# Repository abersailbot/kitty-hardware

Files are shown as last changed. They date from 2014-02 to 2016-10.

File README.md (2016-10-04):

kitty-hardware 
===================================================================================================================================================================

Files relating to Kitty's hardware

This currently contains:

  * [Sails](sails) - Files for the sails
  * [Hull](hull) - Files used in the construction of the hull

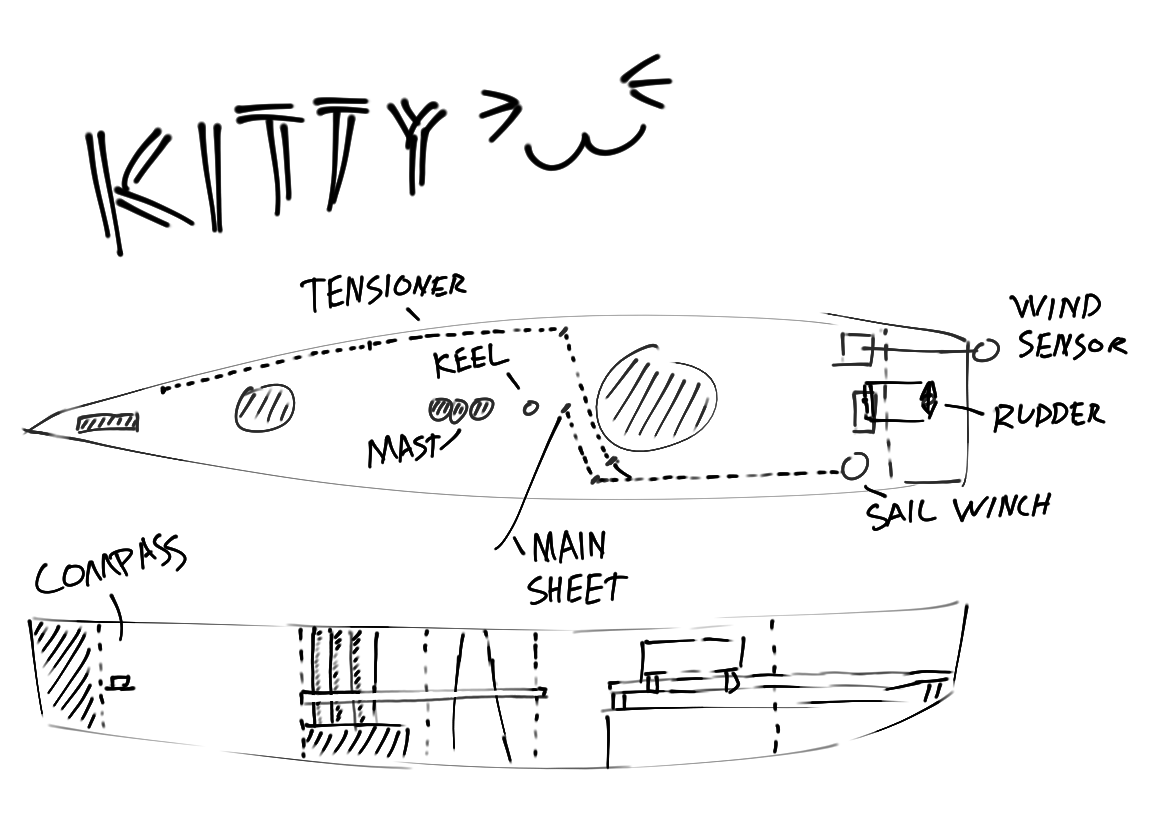
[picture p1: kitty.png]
kitty


Unless specified otherwise, the files contained within are licenced under [CC BY
4.0](http://creativecommons.org/licenses/by/4.0/). See [COPYING](COPYING) for
the full licence.

Weights:
  * Boat with most of the stuff in - 13 kilos
  * Keel - 15 kilos

  * box:
    * base > 29 kilos
    * lid 19 kilos
    * 2.09m x 0.72m x 0.60m

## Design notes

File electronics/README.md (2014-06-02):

Electorics
==========

Box connectors
--------------

###Plug 1
  1. Rudder Power (7.2v)
  2. Rudder Ground
  3. Rudder Servo Data
  4. 
  5. 
  6. Multiplexor Power (6v)
  7. Sail Winch Ground
  8. Sail Winch Live (7.2v)
  9. Sail Winch Data
  10.
  11. Multiplexor Ground
  12.

###Plug 2
  1. Wifi Ground
  2. Wifi Data-
  3. Wifi Data+
  4. Wifi Power (5v)
  5. 
  6. Compass SDA
  7. Compass Ground
  8. Rowind Data
  9. Rowind Ground
  10. Rowind Power (14.4v)
  11. Compass SCL
  12. Compass Power (5v)

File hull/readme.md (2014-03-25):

Hull
----

These are the files used in the construction of the hull.

`hull.igs` was created by [Paul
Miller](http://www.usna.edu/Users/naome/phmiller/), and is public domain.

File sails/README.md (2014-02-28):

sails
=====

Kitty's sails, made using [Sailcut](http://www.sailcut.com/). Currently two sails planned:

  * `heavy_air.saildef` - for heavy winds
  * `light_air.saildef` - for light winds

The sails wrap around the mast, so add an extra 83mm (circumference of the mast)
+ 40mm (leech hem) from the mast edge of the sail.

Output formats for printing are stored in [output](output).

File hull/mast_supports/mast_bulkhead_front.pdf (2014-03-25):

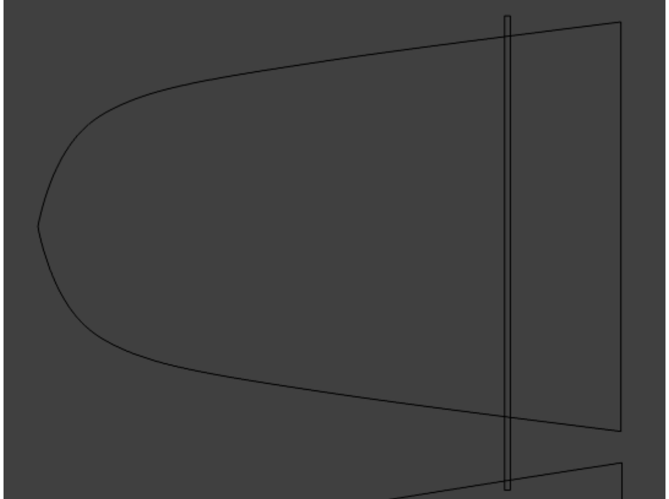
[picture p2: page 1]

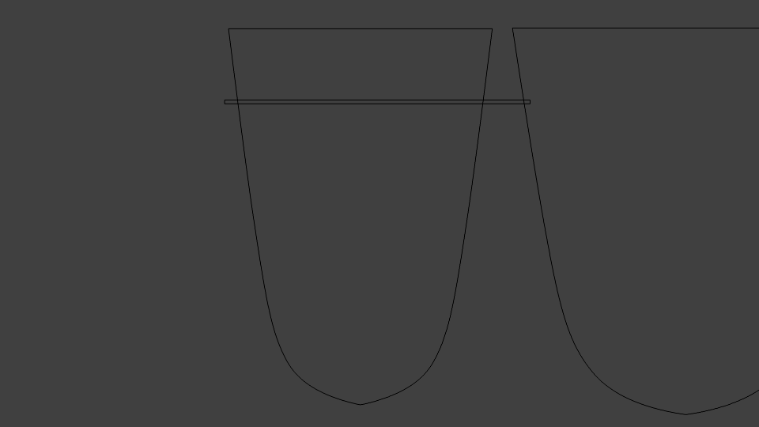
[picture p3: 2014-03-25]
hull/mast_supports/mast_bulkhead.png

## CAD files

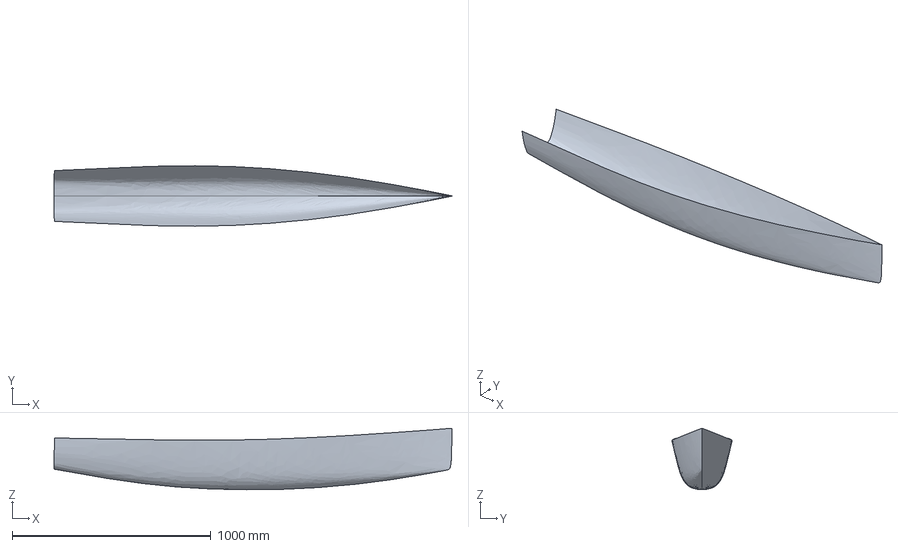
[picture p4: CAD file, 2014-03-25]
hull/hull.igs
2004.0 x 304.7 x 309.7 mm

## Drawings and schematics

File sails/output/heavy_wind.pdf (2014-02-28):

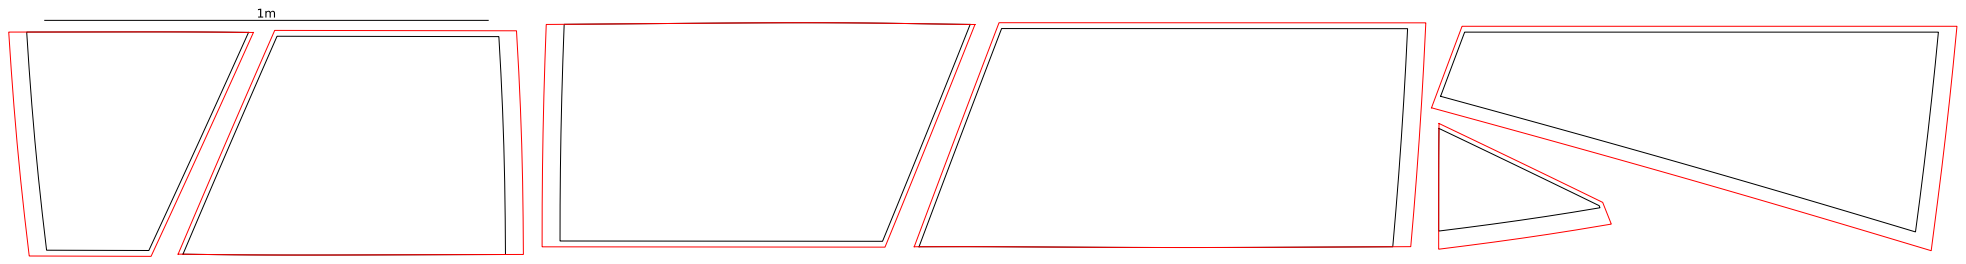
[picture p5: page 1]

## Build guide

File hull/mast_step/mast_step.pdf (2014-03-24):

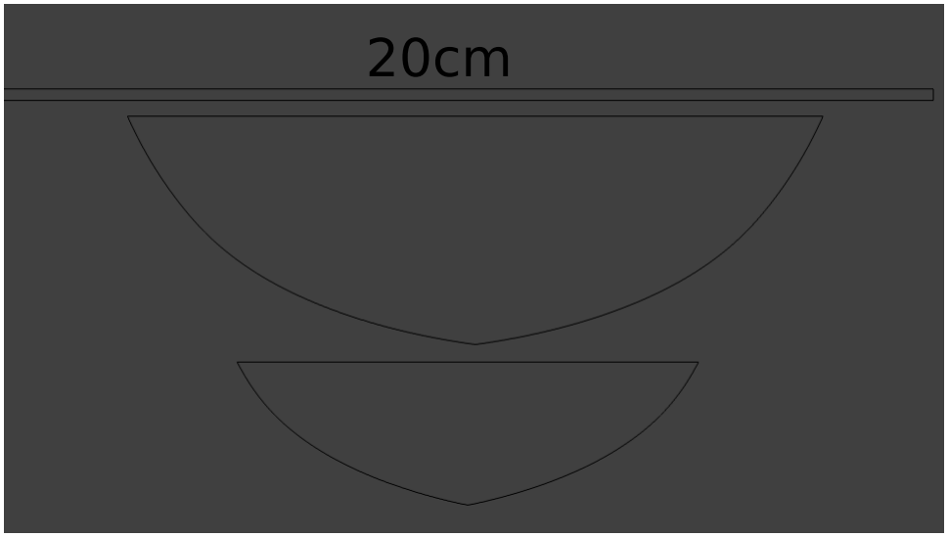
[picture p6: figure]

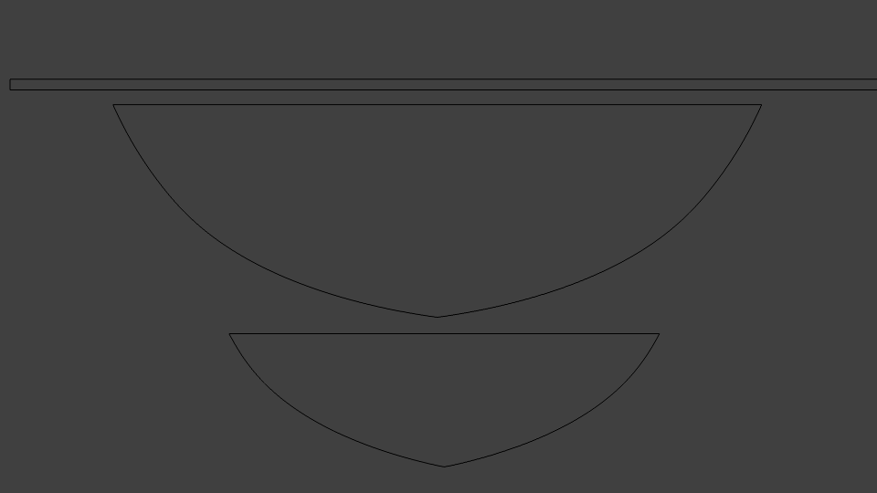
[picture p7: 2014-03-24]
hull/mast_step/mast_step.png

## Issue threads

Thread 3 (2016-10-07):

Investigate Leak

TomGC96, 2016-10-07:
There is a chance that the hull is leaking into the front compartment.

Danyc0, 2016-11-24:
It was first noticed in 2014 in some pretty intense wind, which was pushing the bow well under the water. Testing should probably involve submerging the deck, at least at the bow including past where the the fore-hatch is

ciridae7, 2016-11-30:
We did a water test, found the front hatch was leaking. See issue: https://github.com/abersailbot/kitty-hardware/issues/24

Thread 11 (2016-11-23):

Shopping list

JaffaCakes6, 2016-11-23:
- Nylon screws, bolts, nuts
- Bungee cord elastic stuff (The stuff that's on Dewi)

kragniz, 2016-11-23:
Spray paint for the hull.

kragniz, 2016-11-23:
I just updated the issue to use checkboxes.

JaffaCakes6, 2016-11-30:
Paint for #12, what colour?

naturesyouth, 2016-11-30:
is spray paint the best choice?

ciridae7, 2016-11-30:
O-ring, for front hatch, need to check dimensions. Also vaseline.

Danyc0, 2016-12-01:
@naturesyouth: yea, spray paint will be good. @JaffaCakes6: Kitty is already mostly yellow, I'd guess she just needs more of that

JaffaCakes6, 2017-01-21:
Updated to include more items.

naturesyouth, 2017-01-21:
Are you guys going sand and reprime kitty?

jackwebb6, 2017-02-22:
Undecided. At this point I think we're just going for seafaring paint rather than pretty paint, but I'm not sure.

Also add more items, and purchasing some too.

NicholasRostant, 2017-02-22:
If you're hunting for seafaring paint Marine Enamel is probably what you want.

TomGC96, 2017-02-22:
Yes certainly some sort of marine paint, not any old paint - it'll peel off like crazy.

NicholasRostant, 2017-02-22:
Gelcoat would probably be way too heavy in the kind of thicknesses it's usually applied. I'd recommend something along the lines of [http://www.pettitpaint.com/product.asp?id=274](this stuff), which I've used before, its topside paint but should be more than durable enough.

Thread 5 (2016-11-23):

Secure compass

JSpringett, 2016-11-23:

Danyc0, 2016-11-24:
Please make sure it's an HMC6343, the CMPS10's caused us so much hassle in San Francisco 2014. (Although there is now a CMPS11 which should probably be investigated and TOUGHLY TESTED)

MFrankland, 2016-11-24:
The compass is attached but not quite secure, my hands are too large to properly tighten the screws

adaszymczak, 2016-11-30:
Screws has been changed - issue fixed

Closed 2016-11-30.

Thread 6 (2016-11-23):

Captain Morgan for Kitty

JSpringett, 2016-11-23:

JaffaCakes6, 2016-11-23:
If the bodged Canada board (w/ ribbon cable) works the same, easy peasy.

If not (for now, supposedly), just edit the software to cope.

Danyc0, 2016-11-23:
Please don't use the bodged canada board for Kitty. Spin a new one! The canada board is not very well protected in terms of grounding and reverse polarity protection. Also it's much harder to use for debugging because it's missing some of the more useful LEDs

JSpringett, 2016-11-23:
Its only temporary will we wait for the new board to be sorted out.

naturesyouth, 2016-11-23:
i think its a good idea to use the old shield to get both boats as similar as possible as soon as possible, but given the large number of unknowns in the boat i would feel better if you transplanted the board from dewi into kitty as it is so much safer.

Danyc0, 2016-11-24:
It's also worth considering though, that Kitty has a lot more room in her boxes to fit the old ribbon-cable/stacked version of Captain-Morgan

naturesyouth, 2016-11-24:
yeah but i would feel better trusting kitty to the better assembled 1.2, blowing a pi/battery/anything else would be less than fun, especially as it will be replaced by christmas and we are currently rediscovering how kitty works.

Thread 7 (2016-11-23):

Investigate power source

JSpringett, 2016-11-23:

Danyc0, 2016-11-23:
The ones in kitty are 4*7.2v NiMh. They're in series for the computers to run the RoWind at the right voltage, but in parallel for the servos to give them enough current capacity. (All recalled from 3 year old memories, so take with a pinch of salt)

JSpringett, 2016-11-23:
Cheers Dan

Danyc0, 2016-11-24:
It might be worth switching to having both sets in parallel and using a boost converter to get the voltage needed for the RoWind. This was originally discounted because of the inefficiencies in boost regulators as compared to buck regs, but now, thanks to us having a working PCB (Captain Morgan), it opens lots of doors with regards to very efficient boost regulators. This would allow us to better standardise electronics between the boats (with a Do Not Populate on the boost reg for boats which don't have a RoWind).

naturesyouth, 2016-11-24:
i would be tempted to populated it anyway, that way all the boats are spares for other boats, increasing the available redundancy while at a competition, it can always be disabled through software to save power.

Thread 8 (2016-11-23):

Investigate RC module

JSpringett, 2016-11-23:

JSpringett, 2016-11-23:
Does it still work? How should it be wired up, document!

JaffaCakes6, 2016-11-23:
User manual attached:
[FCCID.io-1160743.pdf](https://github.com/abersailbot/kitty-hardware/files/609309/FCCID.io-1160743.pdf)

Needs trimming down/relevant info retrieving.

Danyc0, 2016-11-23:
I wouldn't use this module, it's super flukey!

Danyc0, 2016-11-24:
The one currently used in Dewi was much more reliable and cheaper too (although alternatives could be looked at for both boats)

Danyc0, 2016-11-24:
Dewi-Hardware issue abersailbot/dewi-hardware#64 talks about getting an RF receiver with an external antennae connection, which would be a cool idea

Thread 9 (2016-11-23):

Investigate Multiplexer

JSpringett, 2016-11-23:

JaffaCakes6, 2016-11-23:
Looks like someone went to town on soldering this, and soldered everything together onto a single track. Anyone know anything about this? Primarily, **does it still work**?
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

Also, link to product page, with some nice information on usage: https://www.pololu.com/product/721

Danyc0, 2016-11-23:
yea, the ground and power lines should be shorted together to give a common ground. It worked last time I saw it!

JaffaCakes6, 2016-11-24:
I'll desolder all the pins and give it a test then!

Danyc0, 2016-11-24:
I'd really suggest not doing that! Desoldering that would be virtually impossible. Just test it without taking of the veroboard.

JaffaCakes6, 2016-11-24:
Argh, so much conflicting information! That's not a bad thing necessarily, though.

I forget who said it, but someone working on Kitty with us yesterday suggested we desoldered it so we could see if it was working, but that it would be very difficult to do.

I'll give it a test, then pawn the decision of desoldering off to someone more experienced, then create a separate issue to go from there. Probably leave this one going in case we need to go an alternative route.

That sounds like a better plan to me, at least.

naturesyouth, 2016-11-24:
the soldering station in the dsl has a solder pump/iron attachment, if it still works it should make short work of desoldering the pins.

Tebazil12, 2016-11-24:
Danyc0 are all the pins connecting to the veriboard ground and power? All 13pins on both rows are soldered together (which can't be seen well here)

Danyc0, 2016-11-24:
I'm not entirely sure what you mean, but all 13 grounds should be connected together

Danyc0, 2016-11-24:
Why does someone want to desolder it anyway?

Tebazil12, 2016-11-24:
There are 13 grounds?

Tebazil12, 2016-11-24:
We wanted to desolder it because it looked like someone soldered everything together when it wasn't meant to be. Is there any documentation anywhere about this?

Danyc0, 2016-11-24:
So each set of three pins is designed to go to a different servo connector(not necessarily a servo, but a servo connector, for example those found on the RC modules). So one row is always ground, and should be common. IIRC this is the only common ground between the servos and the computers. The multiplexor is powered off the 5v power out from the sail which, and then the RC module is powered off the multiplexor (it has to be like that for the winch to work properly).
The ground out of the winch is connected to the multiplexor, and so is the ground from the arduino, which is how we get the common ground.
The rudder servo should not be powered off the multiplexor, it should be powered from the same place as the winch, directly off the battery. Therefore the only power connections to the multiplexor are:
5v Power in from the winch to the multiplexor
Power out to the RC
and therefore it's OK for them to all be connected together.

The data lines should NOT all be connected together, they are as follows:
Data in from the RC (Sail)
Data in from the RC (Rudder)
Data in from the RC (Switch). This is channel 5 and is used to switch between RC and Arduino control. It defaults to arduino control is no signal is detected (e.g RC remote is off or out of range)
Data in from the Arduino (Sail)
Data in from the Arduino (Rudder)
Data out to the winch
Data out to the rudder servo

See the online docs for the multiplexor for more info. Specifically on the importance of the jumper wire, and the difference between master and slave.

Danyc0, 2016-11-24:
The common ground is vitally important to get the arduino controlling the servos

JaffaCakes6, 2016-11-24:
Here is an image of the soldering atop the veriboard. Hopefully you lot can make some more informed decisions from it.
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

JaffaCakes6, 2016-11-24:
I've given it a clean. There's no connection between the two rows, so definitely deliberate.

Danyc0, 2016-11-24:
Yea that's fine, it's just the ground and 5v lines which are joined. It's the 3rd row which shouldn't be joined

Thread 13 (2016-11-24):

Remove Rails and the rail mountings on boxes

Danyc0, 2016-11-24:
Sorry @kragniz but they make it SO much harder to get the boxes in and out

kragniz, 2016-11-24:
RIP our advanced technology: https://www.youtube.com/watch?v=4pei8jrFM2A
:shipit:

CloudCoppola, 2016-11-30:
Rails and rail mounts on main big box have been removed - issue fixed
Are there other boxes?

Danyc0, 2016-12-01:
:'( end of an era :P

Closed 2016-11-30.

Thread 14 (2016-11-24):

Find all the screws/pins for the box lids

Danyc0, 2016-11-24:
IIRC there are some of the screw/pin things missing which are used to close the lid on Kitty's boxes

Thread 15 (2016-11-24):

Investigate CMPS11

Danyc0, 2016-11-24:
The CMPS10s are really useless, but there is a new version, the CMPS11, which should probably be tested as a much cheaper alternative to the HMC6343. And when I say tested, I mean super heavily tested, because the testing we did on the CMPS10's in 2014 was not good enough, because it didn't throw up the issues until Sailbot2014, at which point we had no replacement.

naturesyouth, 2016-11-24:
surely the best way to test this would be to have all three fixed to the same boat and then comparing the data they spit out when actually testing the boats.

kragniz, 2016-11-24:
Building a board (literal board, not a pcb) with all three attached would also do the same thing and doesn't require physically attaching them into a boat.

Danyc0, 2016-11-24:
We did that test, on a board, back in 2014, between the CMPS10 and the HMC6343, it put the CMPS10 as "good enough", however later experience tells us that was not the case!

naturesyouth, 2016-11-24:
true, but adding them into dewi and then running her on some actual sailing tasks would give real world data

Danyc0, 2016-11-24:
Real world data would not have detected the CMPS10 issue. It needs to be long term testing, running for days, a week maybe. As well as comparisons with the HMC6343.

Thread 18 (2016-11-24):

Use fewer USB ports

Danyc0, 2016-11-24:
Kitty used so much USB that she needed a USB hub to operate. The USB hub was messy, big, and was a big extra source of possible problems.

The devices she needs are as follows:
Wifi host (same as in dewi)
Wifi client (same as in dewi)
GPS (same as in dewi)
Arduino (same as in dewi)
RoWind

The need for a hub was in part because she was built using a Pi B, so only had 2 USB ports to start with. However even with the extra 2 ports gained in the B+ and above, it's still not enough to go without a hub. Thanks to Captain morgan, the GPS has been moved to the Pi's (only) serial port, however that port used to be used by the xBee, which now has to go via USB, so they have just swapped.

The main problem is that the RoWind has an RS232 interface, and therefore we opted to use an RS232-USB converter. An alternative would be to use a Logic-Level-Converter and pass the data into another serial port, however you have to be very careful with that because the voltage levels in RS232 are 0 to -12V (and also 0 to 12V as a twisted pair), the Pi uses 3.3V serial (I think, It could be 5V, but I don't think so, it's worth checking) and the Arduino uses 5v serial (again, I think, but worth checking it's not 3.3V). So care must be taken to get a converter which can deal correctly with the conversion from RS232 to the correct 3.3V/5V serial. The biggest problem with this however is that there are no free serial ports anywhere in the setup, because the Pi's is used by the GPS via Captain Morgan, and the Arduino talks to the Pi over USB (which uses up the Arduino serial port). A possible idea would be to use Software Serial on the Pi or the Arduino, but either option would need EXTENSIVE testing in the real boat, because software serial has a big habit of screwing up servo/PWM channels in the Arduino (but only temperamentally), because they use the same timer internally (there are fixes for this involving editing the serial code to use a different timer, or not using a separate timer at all, but they need proper testing). Also software serial on a not Real Time Operating System on a device like the Pi will often end up going badly because the scheduler will often decide the code generating the serial needs to be paused to let another process run, therefore screwing up the comms.

Have fun with this one!

naturesyouth, 2016-11-24:
while performing my nightly dredging of component suppliers i stumbled across this chip
https://www.maximintegrated.com/en/products/interface/controllers-expanders/MAX14830.html
that uses spi to control 4 uarts.
i would suggest using this to interface with the arduio (atmega328, gps and an rs-232 transiever ic, then hook the xbee up to the native uart, this would allow the pi to boot with a serial monitor at all times, which would be an improvement over the current system.
and the best part?
https://github.com/torvalds/linux/blob/master/drivers/tty/serial/max310x.c
DRIVERS!!!

Danyc0, 2016-11-24:
We can't use the Arduino over anything except USB, because we need it to be programmable from the Pi, but otherwise that sounds like a nice idea, although we have got to be a bit careful about PCB complexity.

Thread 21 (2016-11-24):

Ensuring all wiring follows the wiring standard

Danyc0, 2016-11-24:
There is a wiring standard in the Management repository which should be followed: https://github.com/abersailbot/management/blob/master/sailbot-wiring-standard.md

Danyc0, 2016-11-24:
See comments on abersailbot/dewi-hardware abersailbot/dewi-hardware/issues/40#

jackwebb6, 2017-10-02:
Kitty should be getting a total rewrite, so we can get it to spec then

Danyc0, 2017-10-03:
Why has this been closed despite not being completed?

Closed 2017-10-02.

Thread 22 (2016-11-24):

Check rudder servo

Danyc0, 2016-11-24:
The rudder servo in this boat has always been a little bit flukey. It was the only 'waterproof' servo available at the time which could deal with the torque we needed to move the rudder Kitty has.

The servo is NOT IP rated (Dewi's is!), and is pretty expensive. When new it is all metal gear except one plastic gear, which has broken twice, so IIRC the servo currently fitted in kitty was opened, and had the plastic gear replaced with a metal gear of the same size which was salvaged out of the other broken servo. Due to it's size and torque requirements, this servo draws a tonne of current, so much so that it often caused issues of rebooting the sail-winch when it was working hard (although I think this might have been fixed, but I don't know how).

There are now IP rated servo's on the market for a good price which provide the torque needed, and are much smaller physically. These should be much more reliable as well so I really advise looking into them.
The torque needed can also be significantly reduced by drilling out the mounting hole for the rudder slightly (and when I mean slightly, I mean VERY, VERY slightly, we're talking microns). It's a very stiff fit at the moment, but it cannot be drilled out so far that it wobbles (like, at all), as that would cause horrendous forces in places you really don't want them.

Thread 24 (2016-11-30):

Replace front hatch O-ring

ciridae7, 2016-11-30:
Front hatch is leaking, also buy vaseline to help seal.

JaffaCakes6, 2016-11-30:
;)

Danyc0, 2016-12-01:
We should already have a big tub of Vaseline somewhere in one of the labs.

Danyc0, 2016-12-01:
#25 might be a more permanent solution if it works

Tebazil12, 2016-12-01:
#25 addresses a separate leak. This leak is where the hatch wont seal around the lid when its screwed on (so probably a faulty o-ring). The possible leak in #25 is around where the hatch attaches to the deck (like we found on Dewi at sailbot '16). Both are separate leaks and both need fixing.

Danyc0, 2016-12-01:
How did you conclude they were different leaks and both existed?

Tebazil12, 2016-12-01:
This one definitely exists as water was under the lid (between lid and oring, and running down into the boat) after the water test. The other leak may or may not exist (the hatch appears to be coming away from the deck though, so its worth sealing it just in case).

Danyc0, 2016-12-01:
Good plan!

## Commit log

2014-02-24 Add svg for A1 printing
2014-03-24 Add hull .blend and mast step measurements
2014-03-25 Add hull.igs
    [hull.igs]
2014-04-17 Add pin information

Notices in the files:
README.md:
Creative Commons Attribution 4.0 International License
